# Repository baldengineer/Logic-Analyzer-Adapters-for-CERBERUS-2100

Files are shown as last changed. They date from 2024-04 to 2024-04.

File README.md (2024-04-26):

# CERBERUS 2100 Logic Analyzer Adapters
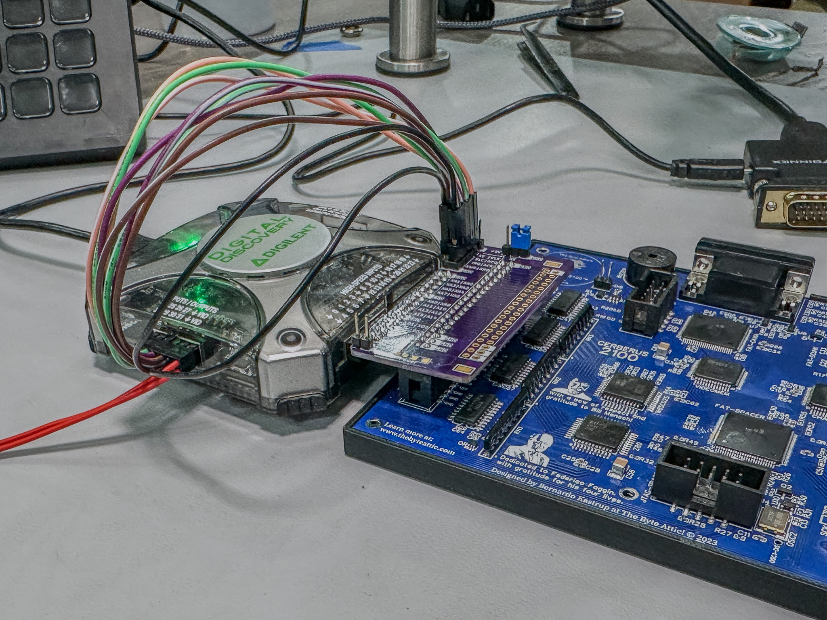
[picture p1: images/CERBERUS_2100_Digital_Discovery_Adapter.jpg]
Digital Discovery Adapter Connected


These adapters allow you to connect a logic analyzer to the CERBERUS 2100 expansion port--while having an expansion board connected.

For more information on the computer, check out the [CERBERUS 2100 project page](https://www.thebyteattic.com/p/cerberus-2100.html).

## One-To-One Adapter 
This adapter replicates the CERBERUS 2100's expansion port three times. Pins are mapped "1 to 1" across all three.

## Digital Digital Discovery Adapter
This adapter connects directly to a Digilent Digital Discovery and an expansion board. The signals on the left are grouped to match the input of the Digital Discovery.

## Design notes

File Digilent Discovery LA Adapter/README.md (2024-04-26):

## Digilent Discovery LA Adapter
Digital Discovery Adapter Connected

This adapter is inteded to be used with a [Digilent Digital Discovery](https://digilent.com/shop/digital-discovery-portable-usb-logic-analyzer-and-digital-pattern-generator/). (Not the Analog Discovery!) These are USB-based logic analyzers that sample up to 100 MHz and 32 signals.

The center connector plugs into the socket. The right connector is for an expansion card. The left connector is for the Digital Discovery. 

Three connection options:
1. Use a short ribbon cable.
2. Mount the header upside-down.
3. Mount the header top-side-up.

### Waveforms Project File
Use the latest [beta version of Waveforms](https://forum.digilent.com/topic/8908-waveforms-beta-download/).

There is a bug with the pattern trigger. Addresses are reversed. So, to trigger on `0x0205` (`0000 0010 0000 0101`) you need to set the pattern to `0xA040` (`1010 0000 0100 0000`).

The clocks and control signals connect to the 24-32 inputs.

**CERBERUS 2100 Digital Discovery Template.dwf3work** is a starting project. It has all of the signals mapped for you! 

### Build Notes
Easily connect a Digilent Digital Discovery to a CERBERUS 2100. At a minimum, you'll need a 40-pin socket and a right-angle 32-pin socket. To act as an interposer between the CERBERUS and expansion card, you need a 40-pin header. There's also a spot for a 0805 resistor and 1206 LED for bling.

### OSH Park Link
The KiCad design files and PCB gerbers are available. Or you can order these boards directly from [OSH Park using this link](https://oshpark.com/shared_projects/0LsKYepP).

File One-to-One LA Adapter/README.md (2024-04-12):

## One-To-One Adapter
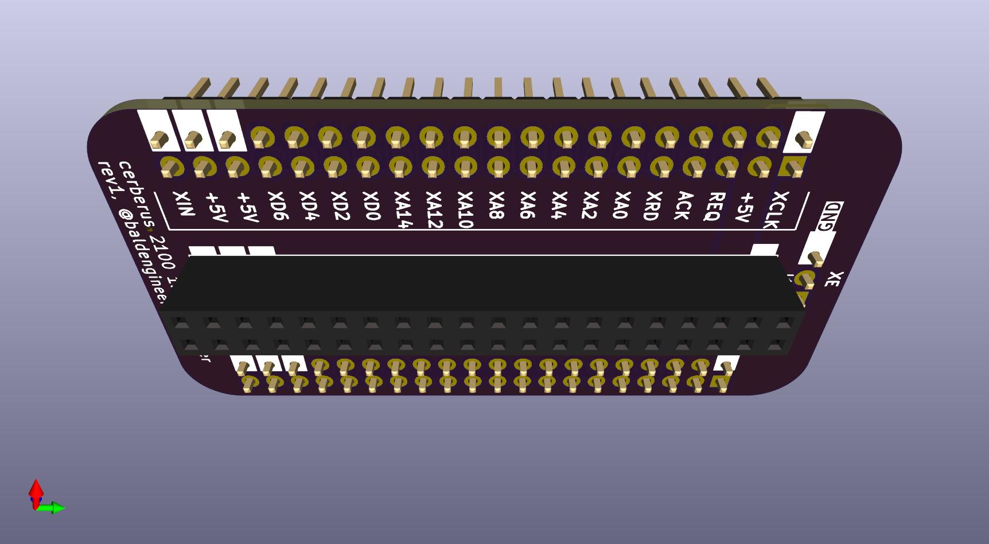
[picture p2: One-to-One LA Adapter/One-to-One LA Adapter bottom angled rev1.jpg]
One-to-One Adapter Bottom


The One-to-one has three connectors. The middle connector plugs into the CERBERUS 2100's socket. The left header is intended for a logic analyzer. The right header is intended for an expansion board.

However, all three headers are connected in parallel.

### Status
Rev1 sent to fab. Still need to make Waveforms template and test the boards.

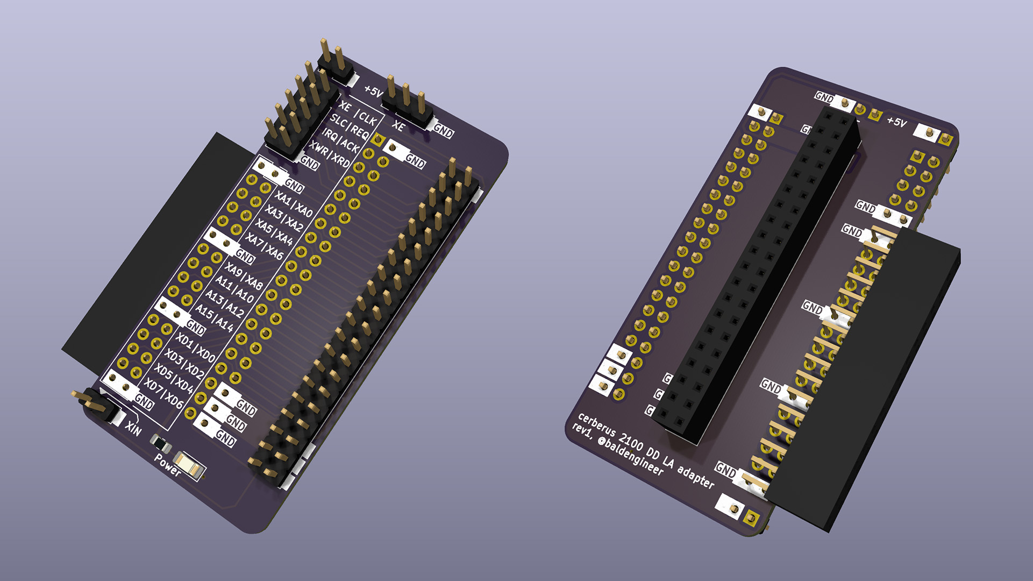
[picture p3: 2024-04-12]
Digilent Discovery LA Adapter/DD_LA_Adapter_top_and_bot_rev1.jpg

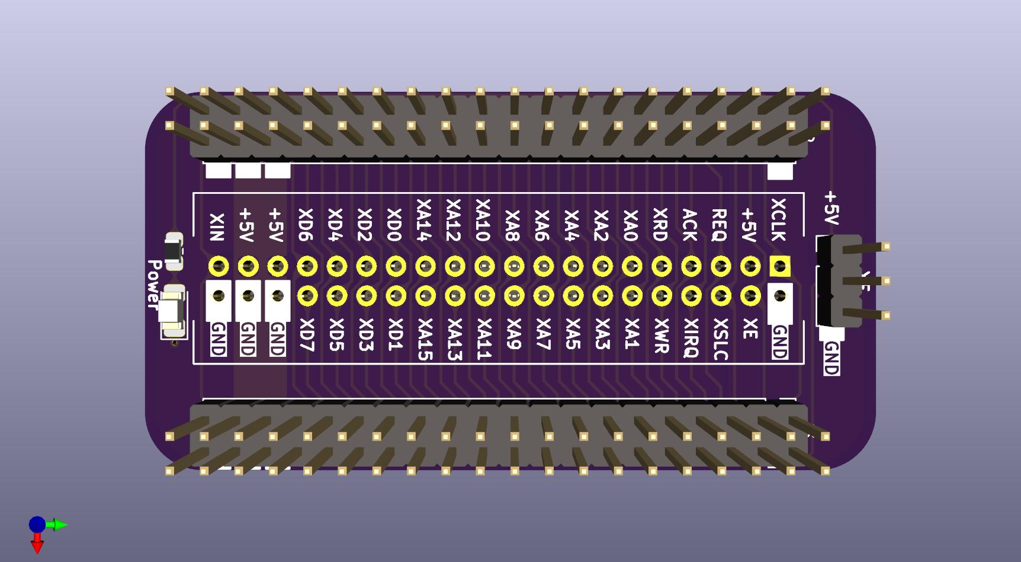
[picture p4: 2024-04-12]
One-to-One LA Adapter/One-to-One LA Adapter top rev1.jpg

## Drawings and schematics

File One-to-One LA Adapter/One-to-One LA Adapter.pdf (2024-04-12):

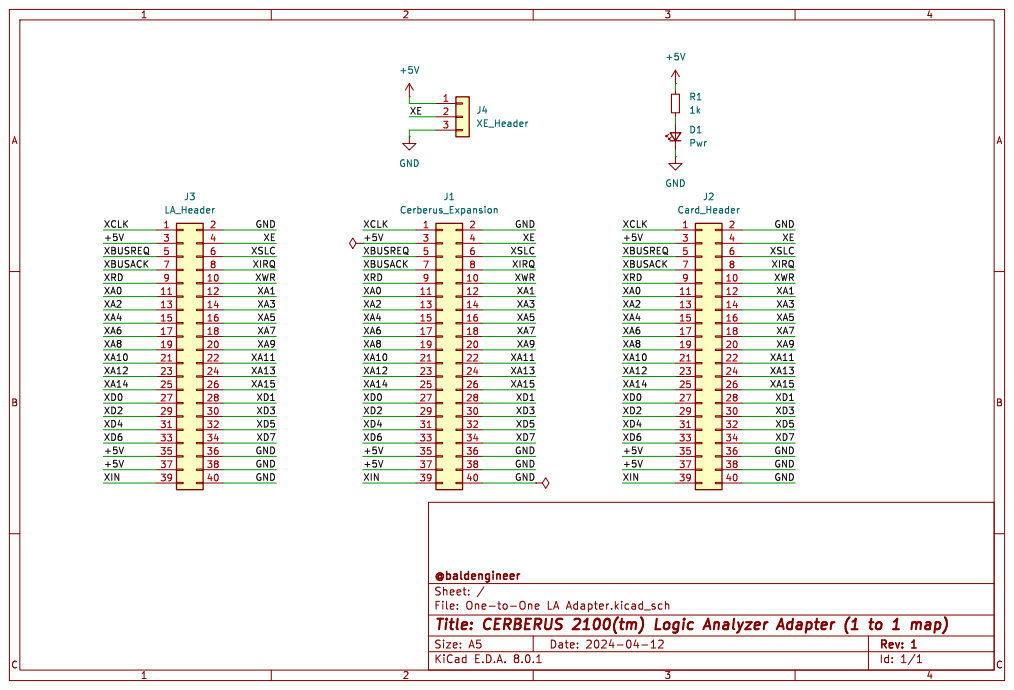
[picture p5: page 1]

J3 | | D1Pwr 1

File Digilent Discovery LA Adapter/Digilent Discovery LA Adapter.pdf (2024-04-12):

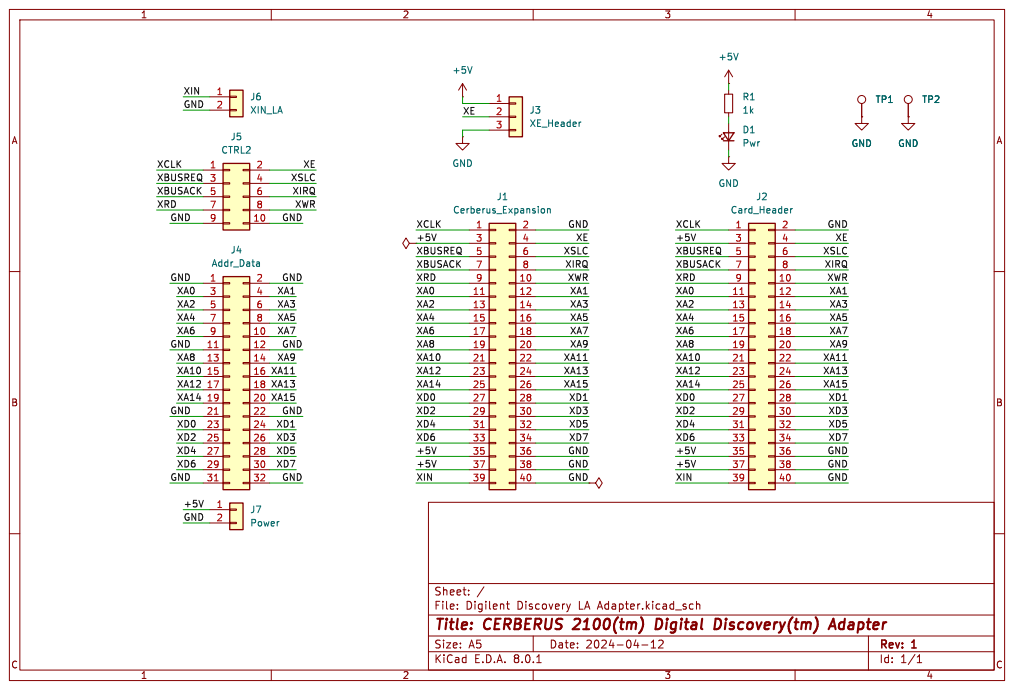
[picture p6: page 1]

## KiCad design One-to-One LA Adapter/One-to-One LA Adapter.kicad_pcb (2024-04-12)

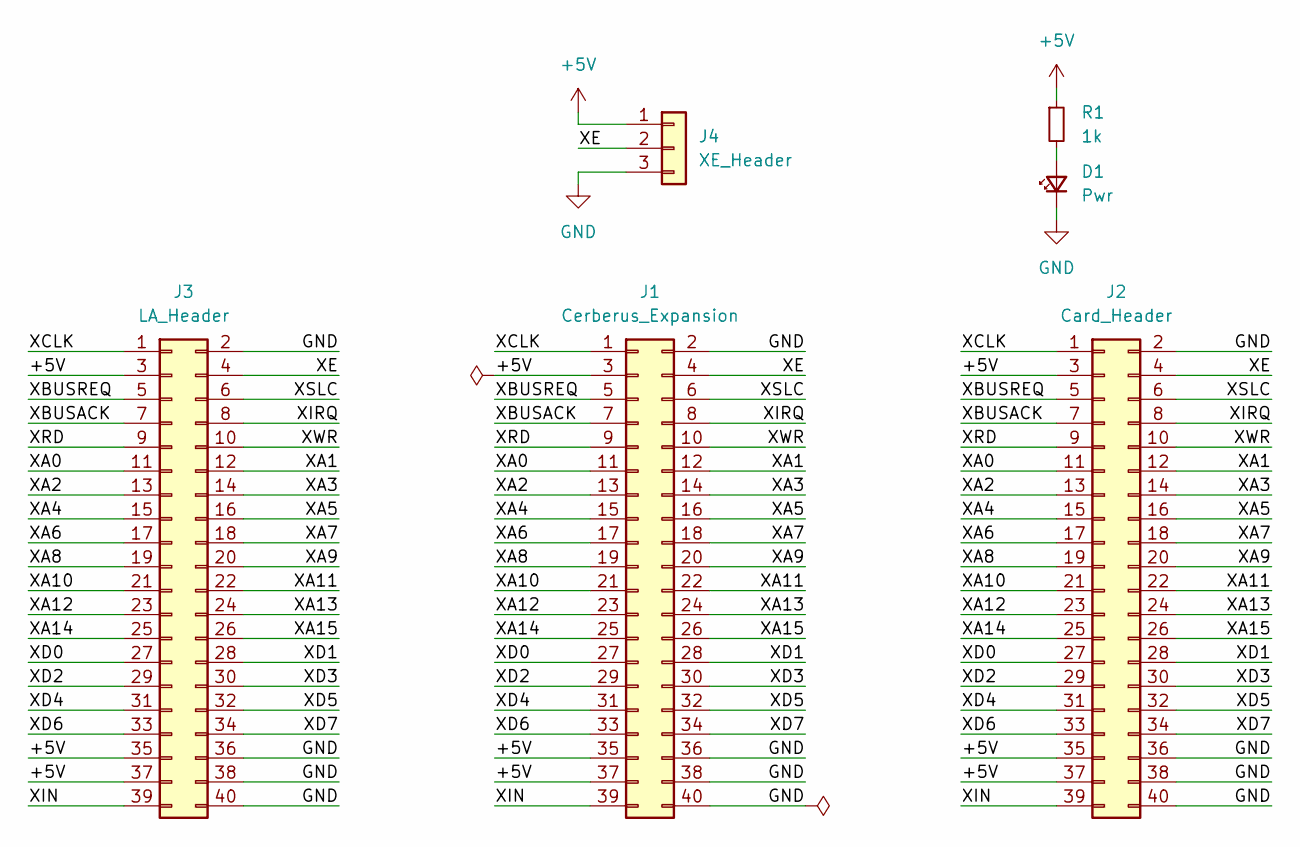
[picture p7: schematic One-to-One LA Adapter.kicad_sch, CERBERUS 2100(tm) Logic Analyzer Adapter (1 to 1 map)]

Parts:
D1: Pwr; LED_1206_3216Metric_Pad1.42x1.75mm_HandSolder
J1: Cerberus_Expansion; PinSocket_2x20_P2.54mm_Vertical
J2: Card_Header; PinHeader_2x20_P2.54mm_Vertical
J3: LA_Header; PinHeader_2x20_P2.54mm_Vertical
J4: XE_Header; PinHeader_1x03_P2.54mm_Vertical
R1: 1k; R_0805_2012Metric_Pad1.20x1.40mm_HandSolder

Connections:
+5V: J1.3, J1.35, J1.37, J2.3, J2.35, J2.37, J3.3, J3.35, J3.37, J4.1, R1.1
/XA0: J1.11, J2.11, J3.11
/XA1: J1.12, J2.12, J3.12
/XA2: J1.13, J2.13, J3.13
/XA3: J1.14, J2.14, J3.14
/XA4: J1.15, J2.15, J3.15
/XA5: J1.16, J2.16, J3.16
/XA6: J1.17, J2.17, J3.17
/XA7: J1.18, J2.18, J3.18
/XA8: J1.19, J2.19, J3.19
/XA9: J1.20, J2.20, J3.20
/XA10: J1.21, J2.21, J3.21
/XA11: J1.22, J2.22, J3.22
/XA12: J1.23, J2.23, J3.23
/XA13: J1.24, J2.24, J3.24
/XA14: J1.25, J2.25, J3.25
/XA15: J1.26, J2.26, J3.26
/XBUSACK: J1.7, J2.7, J3.7
/XBUSREQ: J1.5, J2.5, J3.5
/XCLK: J1.1, J2.1, J3.1
/XD0: J1.27, J2.27, J3.27
/XD1: J1.28, J2.28, J3.28
/XD2: J1.29, J2.29, J3.29
/XD3: J1.30, J2.30, J3.30
/XD4: J1.31, J2.31, J3.31
/XD5: J1.32, J2.32, J3.32
/XD6: J1.33, J2.33, J3.33
/XD7: J1.34, J2.34, J3.34
/XE: J1.4, J2.4, J3.4, J4.2
/XIN: J1.39, J2.39, J3.39
/XIRQ: J1.8, J2.8, J3.8
/XRD: J1.9, J2.9, J3.9
/XSLC: J1.6, J2.6, J3.6
/XWR: J1.10, J2.10, J3.10
GND: D1.1 (K), J1.2, J1.36, J1.38, J1.40, J2.2, J2.36, J2.38, J2.40, J3.2, J3.36, J3.38, J3.40, J4.3
unnamed: D1.2 (A), R1.2

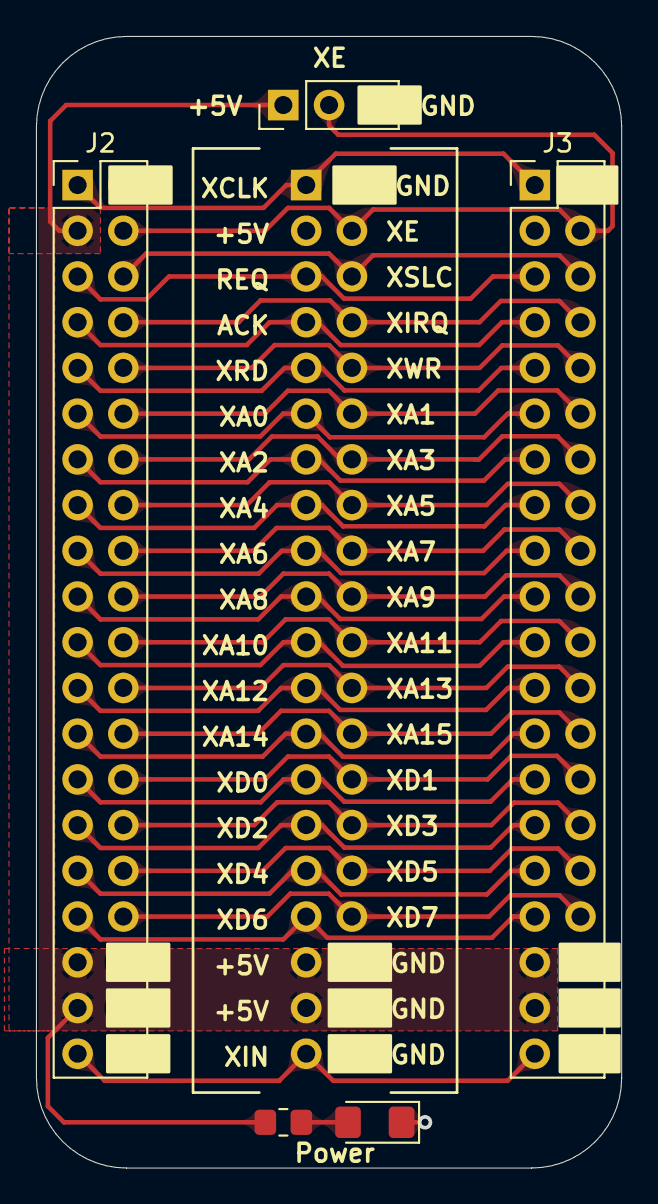
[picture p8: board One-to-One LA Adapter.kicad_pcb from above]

Board: 2 copper layers, 32.5 x 62.9 mm, 6 parts (1 on the bottom side), 36 nets.

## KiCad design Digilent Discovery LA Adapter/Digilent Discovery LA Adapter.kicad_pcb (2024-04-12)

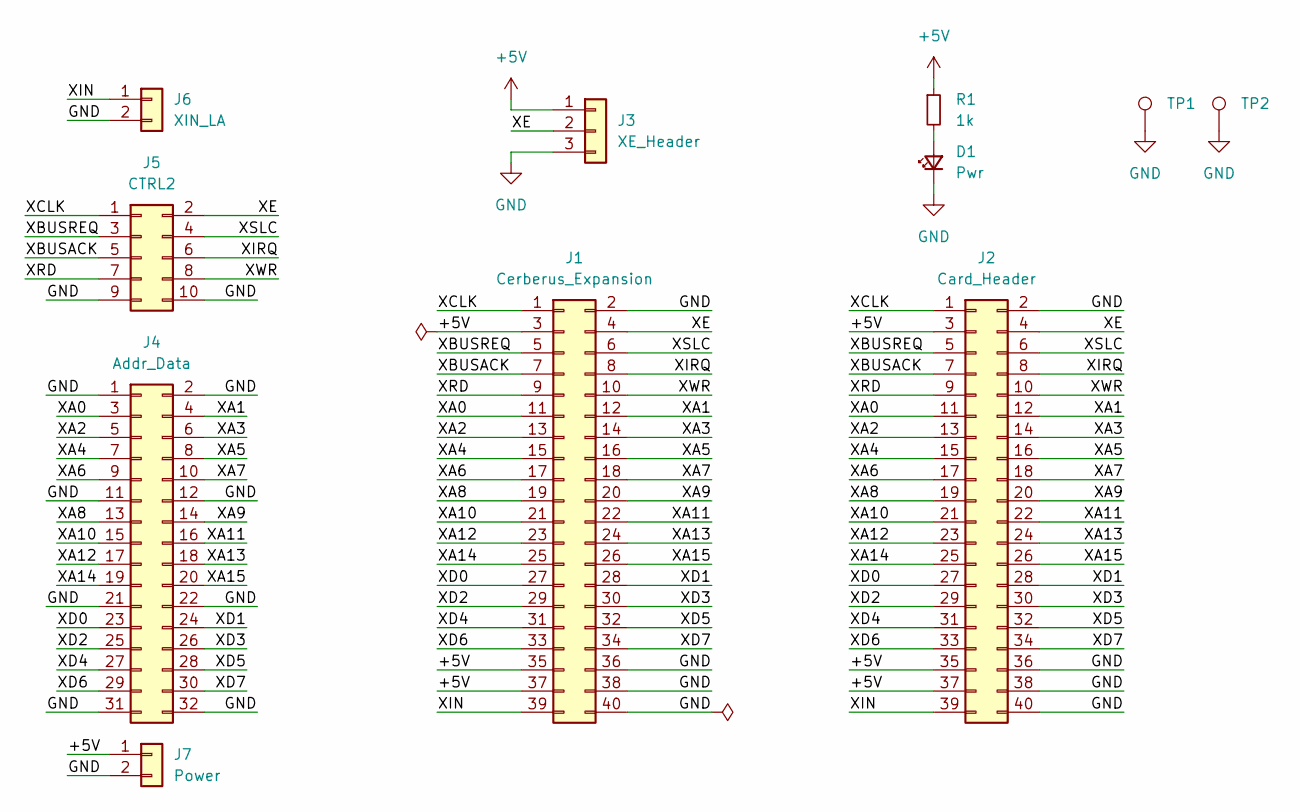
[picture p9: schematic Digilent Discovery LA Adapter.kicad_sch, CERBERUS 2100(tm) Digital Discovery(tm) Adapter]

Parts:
D1: Pwr; LED_1206_3216Metric_Pad1.42x1.75mm_HandSolder
J1: Cerberus_Expansion; PinSocket_2x20_P2.54mm_Vertical
J2: Card_Header; PinHeader_2x20_P2.54mm_Vertical
J3: XE_Header; PinHeader_1x03_P2.54mm_Vertical
J4: Addr_Data; PinSocket_2x16_P2.54mm_Vertical
J5: CTRL2; PinSocket_2x05_P2.54mm_Vertical
J6: XIN_LA; PinHeader_1x02_P2.54mm_Vertical
J7: Power; PinHeader_1x02_P2.54mm_Vertical
R1: 1k; R_0805_2012Metric_Pad1.20x1.40mm_HandSolder
TP1, TP2: TestPoint_Harwin; Harwin-S1751-46-Test-Point

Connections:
+5V: J1.3, J1.35, J1.37, J2.3, J2.35, J2.37, J3.1, J7.1, R1.1
/XA0: J1.11, J2.11, J4.3
/XA1: J1.12, J2.12, J4.4
/XA2: J1.13, J2.13, J4.5
/XA3: J1.14, J2.14, J4.6
/XA4: J1.15, J2.15, J4.7
/XA5: J1.16, J2.16, J4.8
/XA6: J1.17, J2.17, J4.9
/XA7: J1.18, J2.18, J4.10
/XA8: J1.19, J2.19, J4.13
/XA9: J1.20, J2.20, J4.14
/XA10: J1.21, J2.21, J4.15
/XA11: J1.22, J2.22, J4.16
/XA12: J1.23, J2.23, J4.17
/XA13: J1.24, J2.24, J4.18
/XA14: J1.25, J2.25, J4.19
/XA15: J1.26, J2.26, J4.20
/XBUSACK: J1.7, J2.7, J5.5
/XBUSREQ: J1.5, J2.5, J5.3
/XCLK: J1.1, J2.1, J5.1
/XD0: J1.27, J2.27, J4.23
/XD1: J1.28, J2.28, J4.24
/XD2: J1.29, J2.29, J4.25
/XD3: J1.30, J2.30, J4.26
/XD4: J1.31, J2.31, J4.27
/XD5: J1.32, J2.32, J4.28
/XD6: J1.33, J2.33, J4.29
/XD7: J1.34, J2.34, J4.30
/XE: J1.4, J2.4, J3.2, J5.2
/XIN: J1.39, J2.39, J6.1
/XIRQ: J1.8, J2.8, J5.6
/XRD: J1.9, J2.9, J5.7
/XSLC: J1.6, J2.6, J5.4
/XWR: J1.10, J2.10, J5.8
GND: D1.1 (K), J1.2, J1.36, J1.38, J1.40, J2.2, J2.36, J2.38, J2.40, J3.3, J4.1, J4.2, J4.11, J4.12, J4.21, J4.22, J4.31, J4.32, J5.9, J5.10, J6.2, J7.2, TP1.1, TP2.1
unnamed: D1.2 (A), R1.2

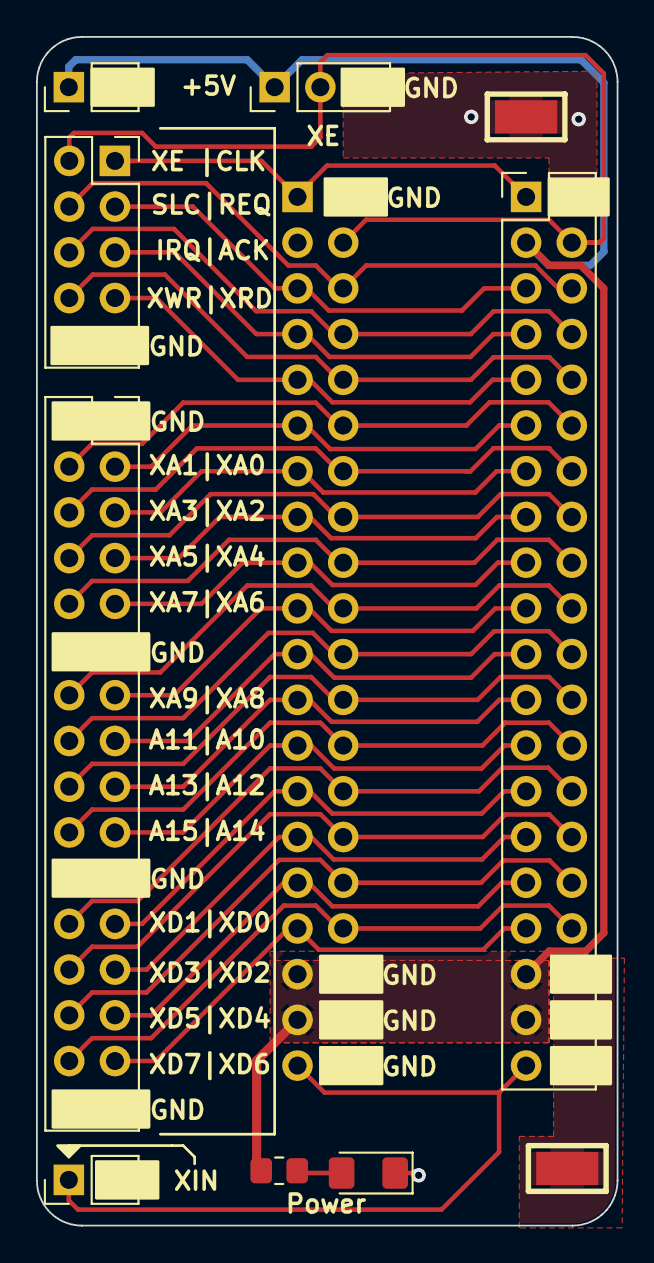
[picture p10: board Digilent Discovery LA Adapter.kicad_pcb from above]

Board: 2 copper layers, 32.3 x 66.0 mm, 11 parts (1 on the bottom side), 36 nets.

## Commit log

2024-04-11 initial commit (for the 1-to-1 adapter)
    [One-to-One LA Adapter.kicad_pcb, One-to-One LA Adapter.kicad_sch]
2024-04-11 initial expansion connector layout
    [One-to-One LA Adapter.kicad_sch]
2024-04-11 one-to-one ready for pcb
    [One-to-One LA Adapter.kicad_sch]
2024-04-12 unrouted 0
    [One-to-One LA Adapter.kicad_pcb, One-to-One LA Adapter.kicad_sch]
2024-04-12 added teardrops
    [One-to-One LA Adapter.kicad_pcb]
2024-04-12 one-to-one rev1 ready for fab
    [One-to-One LA Adapter-B_Cu.gbr, One-to-One LA Adapter-B_Mask.gbr, One-to-One LA Adapter-B_Paste.gbr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]
2024-04-12 initial commit for digital discovery adapter
    [Digilent Discovery LA Adapter.kicad_pcb, Digilent Discovery LA Adapter.kicad_sch]
2024-04-12 Copied Sch headers from Mega IIe
    [Digilent Discovery LA Adapter.kicad_sch]
2024-04-12 cleared net labels
    [Digilent Discovery LA Adapter.kicad_sch]
2024-04-12 labeled DD headers in sch and updated to pcb
    [Digilent Discovery LA Adapter.kicad_pcb, Digilent Discovery LA Adapter.kicad_sch]
2024-04-12 thermal drc "error"
    [Digilent Discovery LA Adapter.kicad_pcb]
2024-04-12 about to delete extra silk
    [Digilent Discovery LA Adapter.kicad_pcb, Digilent Discovery LA Adapter.kicad_sch]
2024-04-12 dd adapter rev 1 ready to go to the fab
    [Digilent Discovery LA Adapter-B_Cu.gbr, Digilent Discovery LA Adapter-B_Mask.gbr, Digilent Discovery LA Adapter-B_Paste.gbr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]
2024-04-12 Documentation updates. (No design changes made.)
    [One-to-One LA Adapter.kicad_pcb, One-to-One LA Adapter.kicad_sch]
